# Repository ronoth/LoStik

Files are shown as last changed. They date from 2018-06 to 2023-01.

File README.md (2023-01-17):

# LoStik

LoStik is an affordable, easy to use, LoRaWAN™ compatible device. It lets IoT (Internet of Things) integrators, network testers, and hobbyists get connected to a LoRa® network faster, diagnose network issues more easily, and build new and exciting connected devices.  LoStik is currently available to purchase on [Crowd Supply](https://www.crowdsupply.com/third-venture/lostik) and [Connected Things Store](https://connectedthings.store/gb/search?controller=search&s=lostik).

## Examples

Python examples require Python 3.  Be sure to install the dependiencies in requirements.txt

    pip install -r requirements.txt

### Miniterm

miniterm.py is a light weight terminal emulator that works well with LoRa stick. 
The RN2903/R2483 radios require \r\n line ending and run at 57600 baud.

    ./miniterm.py --echo /dev/ttyUSB0 57600

### Blinky

blinky.py is for testing the user LEDs on the LoRa Stik.  There is a red led tied to GPIO11 and a blue led tied to GPIO10. 

    ./blinky.py  -m blue -d 1 /dev/ttyUSB0

will blink the blue led once per second

    ./blinky.py -m both -d .5 /dev/ttyUSB0

will alternate the blue and red leds every .5 seconds.

### Packet Radio

radio_receiver.py and radio_sender.py are used for sending LoRa packets between two LoRa Stiks without the need for a LoRaWAN gateway.  The included example sends a unix timestamp packet every 2 seconds and the receiver prints the incoming packets to stdout.

## Resources

For detailed infomation about available commands checkout one of the following docs:
* [RN2903 Command Reference](http://ww1.microchip.com/downloads/en/DeviceDoc/40001811A.pdf)
* [RN2843 Command Reference](http://ww1.microchip.com/downloads/en/DeviceDoc/40001784B.pdf)

### GUI
Microchip offers a programm called "Lora Dev Utility" that is part of the [LoRa Development Suite](https://www.microchip.com/developmenttools/ProductDetails/dv164140-1)

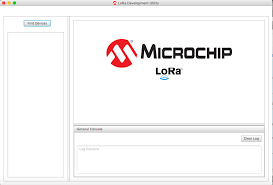
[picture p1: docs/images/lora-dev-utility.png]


## Platform Notes

For platform specific notes see:

* [Windows](docs/windows.md)
* [Mac](docs/mac.md)
* [Linux](docs/linux.md)

## License

### Software

All software and example scripts are MIT licensed.  For details see [LICENSE](blob/master/LICENSE)

### Hardware
Hardware design and schematics are licenede under Creative Commons CC-BY-SA-NC  For details see [hardware/LICENSE.md](blob/master/hardware/LICENSE.md)

### User LEDS

LoStik has two user LEDs that you can control via the UART interface on GPIO10 and GPIO11 and can be accessed using the following commands:

```sys set pindig GPIO10 1``` (turns on blue LED)

```sys set pindig GPIO10 0``` (turns off blue LED)

```sys set pindig GPIO11 1``` (turns on red LED)

```sys set pindig GPIO11 0``` (turns off red LED)

<sup>LoRa® and LoRaWAN™ are trademarks of Semtech Corporation or its subsidiaries.</sup>

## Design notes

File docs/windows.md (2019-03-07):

# CH340G Driver

Windows requires the installation of the CH340 USB to Serial Driver.  [Download Link](http://www.wch.cn/downloads/file/65.html)

Once installed you should should see a new COM port in device manager that appears as a CH340 serial device.

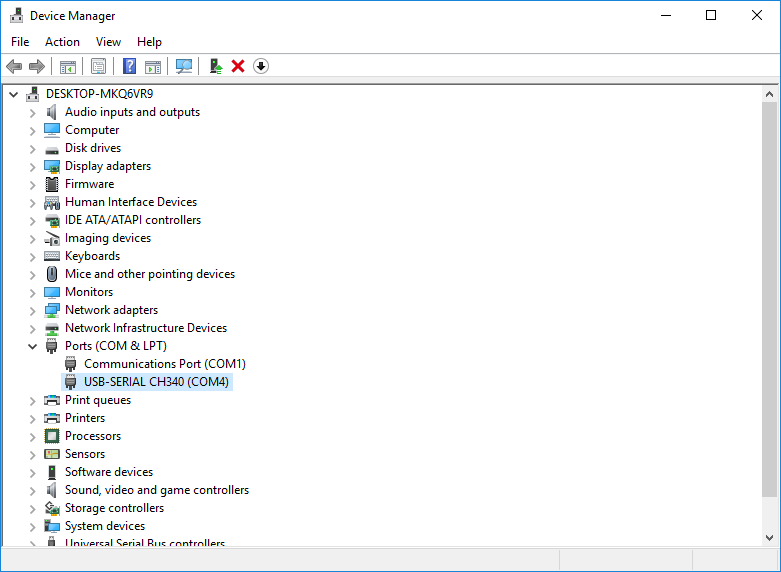
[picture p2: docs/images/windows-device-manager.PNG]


# Terminals

* **Termite** - [Termite](https://www.compuphase.com/software_termite.htm) is a friendly terminal emulator and is the recommended route if you do not wish to install python.  Besure to check the options below, including `Append CR-LF` and `Local echo`.

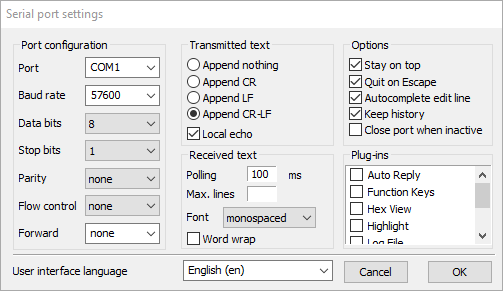
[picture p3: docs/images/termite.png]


* **miniterm.py** - [examples/miniterm.py](../examples/miniterm.py) is a python terminal emulator that is recommended for use along with the python examples provided in this repository.
* **Putty** - Although Putty is very popular, the RN2903/RN2483 require \r\n endings which is not a configuration option in vanilla putty.

# GUI
Microchip offers a programm called "Lora Dev Utility" that is part of the [LoRa Development Suite](https://www.microchip.com/developmenttools/ProductDetails/dv164140-1)



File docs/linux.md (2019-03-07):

# Driver

Most modern Debian distros come with the CH340 serial driver compiled as a kernel module.  WCH offers [Linux driver source](http://www.wch.cn/download/CH341SER_LINUX_ZIP.html), but compilation and installation is not covered here.

# Terminal

There is a python terminal utility located in examples/miniterm.py that is recommended.

Any terminal emulator that can send \r\n should work.  Key settings are:
* baud: 57600
* data bits: 8
* stop bits: 1
* parity: none
* flow control: none

# GUI
Microchip offers a programm called "Lora Dev Utility" that is part of the [LoRa Development Suite](https://www.microchip.com/developmenttools/ProductDetails/dv164140-1)



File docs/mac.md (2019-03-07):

# CH340G Driver

Mac OS X requires the installation of the CH340 USB to Serial Driver.  Please refer to the following repository for installation instructions:

https://github.com/adrianmihalko/ch340g-ch34g-ch34x-mac-os-x-driver

# Terminals

There is a python terminal utility located in examples/miniterm.py that is recommended.  The `screen` commandline utility will also work.  The serial device will be mounted to in the dev directory and appear as `tty.wchusbserial14210` or similar.  

Any terminal emulator that can send \r\n should work.  Key settings are:
* baud: 57600
* data bits: 8
* stop bits: 1
* parity: none
* flow control: none

# GUI
Microchip offers a programm called "Lora Dev Utility" that is part of the [LoRa Development Suite](https://www.microchip.com/developmenttools/ProductDetails/dv164140-1)



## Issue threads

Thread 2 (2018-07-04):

expand README

vielmetti, 2018-07-04:
Some things I'd expect to see in a README

- what this code is for
- who wrote it
- where you can order these parts
- when things are expected to ship
- why you might want it
- what else you might build on top of this system

vielmetti, 2018-07-04:
Some of the details and pictures from https://www.thethingsnetwork.org/forum/t/lora-stik-rn2903-usb-device/14976 would be good to add here too.

vielmetti, 2018-07-04:
Some reference to the RN2903 data sheet at http://ww1.microchip.com/downloads/en/DeviceDoc/50002390E.pdf would be useful too.

lolsborn, 2018-07-09:
Thanks @vielmetti  I have plans to add more example code and an updated read me in the following weeks before the CS campaign closes.

WA4OSH, 2018-12-01:
Some reference to the RN2483 data sheet would also be good for EU868 users.

WA4OSH, 2018-12-01:
Some reference to the PIC18F46K22 is needed
https://www.microchip.com/wwwproducts/en/PIC18F46K22
http://ww1.microchip.com/downloads/en/DeviceDoc/40001412G.pdf

WA4OSH, 2018-12-01:
Some reference to the LoRaWAN Library is needed:
http://ww1.microchip.com/downloads/en/DeviceDoc/40001864B.pdf

WA4OSH, 2018-12-01:
Your LoStik API needs to be documented
  send_cmd(" ")...

  sys set pindig GPIO11 0
      GPIO10 = blue led
      GPIO11 = red led
      0 = off?
      1 = on?

  sys get ver

  radio get freq
  radio get mod
  radio get sf

  radio rx

  radio set pwr 10

...etc.

Where are the LoRaWAN commands?  Are there callbacks to handle the incoming LoRaWAN messages?

lolsborn, 2018-12-01:
Check out the command references linked to in the readme.  

On Sat, Dec 1, 2018 at 11:49 AM -0800, "Konrad Roeder" <notifications@github.com> wrote:

Your LoStik API needs to be documented

send_cmd(" ")...

sys set pindig GPIO11 0

GPIO10 = blue led

GPIO11 = red led

0 = off?

1 = on?

sys get ver

radio get freq

radio get mod

radio get sf

radio rx

radio set pwr 10

...etc.

Where are the LoRaWAN commands?  Are there callbacks to handle the incoming LoRaWAN messages?

—
You are receiving this because you commented.
Reply to this email directly, view it on GitHub, or mute the thread.

WA4OSH, 2018-12-05:
@lolsborn  OK ... then please document at least the action of the system commands that won't be documented in the Microdot document.  For example, there's no indication in the microdot documentation as to which LEDs are connected to what ports.  Yes, I can read a schematic.  But, it's sometimes good to have it all in one place.  Documentation does not need to be a research project for the user.

sys set pindig
GPIO10 = blue led
GPIO11 = red led
0 = off?
1 = on?

lolsborn, 2018-12-08:
Try just sending "sys get ver" to start.  If that doesn't return a
version string then you then you may have an issue with your unit.Sending random text will also return "invalid_command".    Otherwise
your terminal settings look correct.

On Sat, Dec 8, 2018, at 5:28 AM, Konrad Roeder wrote:
> Need a quick "sanity check" for LoStik.

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

Links:

  1. https://github.com/lolsborn/LoStik/issues/2#issuecomment-445459253
  2. https://github.com/notifications/unsubscribe-auth/AADshKnf4MvM_Dock81CCGEflLxNYXU8ks5u276NgaJpZM4VB4Mm

lolsborn, 2018-12-08:
There is a miniterm.py in examples that works well as a test terminal.
If you run python miniter.py <COMPORT> 57600 it is a good way to see if
it's an issue with your existing terminal settings.

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

Links:

  1. https://github.com/lolsborn/LoStik/issues/2#issuecomment-445475790
  2. https://github.com/notifications/unsubscribe-auth/AADshJAOq8612aHca11q8xAIsYhrAeW3ks5u2_cEgaJpZM4VB4Mm

WA4OSH, 2018-12-08:
I had not setup Python 3.7.1 on my machine yet and needed something quicker
to check my LoStik.  Next step, is of course to finish getting Python up
and running.

--Konrad

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

--
Best,
Konrad

Konrad Roeder
425-444-0595 Cell
425-256-2144 Home

lolsborn, 2018-12-09:
Added info about LEDs to readme and have updated docs / examples quite a bit since this ticket was initially created.  I'm going to close it for now.  If there are specific suggestions or PRs please open another issue.

Closed 2018-12-09.

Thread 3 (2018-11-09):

radio_sender.py: invalid_param

dl8bb, 2018-11-09:
Hi folks,
  today I got the two LoStiks from customs and I'm happy to try it out. I cloned the repo and started trying the examples. blinky.py is working with both sticks but I have not much luck with radio_sender.py and radio_receiver.py scripts. It looks like the sender is only working the 1st time and than it says "*invalid_param*" forever.

Here is the output I see:

```
pi@pinebook:~/LoStik/examples$ ./radio_sender.py
ok
RN2483 1.0.4 Oct 12 2017 14:59:25
lora
868100000
sf12
4294967245
ok
ok
ok
ok
ok
radio_tx_ok
ok
invalid_param
ok
ok
invalid_param
ok
ok
invalid_param
ok
ok
invalid_param
^CTraceback (most recent call last):
  File "./radio_sender.py", line 26, in <module>
    time.sleep(2)
KeyboardInterrupt
pi@pinebook:~/LoStik/examples$
```

and the receiver is on a pi2

```
pi@raspberrypi:~/LoStik/examples $ ./radio_receiver.py
connection made
RN2483 1.0.4 Oct 12 2017 14:59:25
4294967245
radio_rx  1541778041
```

Any hints or help for me?

BTW: I modified the parser.add_arguments() call in both files to
```
parser.add_argument('port', nargs='?', default='/dev/ttyUSB0', help="Serial port descriptor")
```
cheers
birko
--

dl8bb, 2018-11-09:
I've added some debug output to the radio_sender.py script and it looks like at some point the LoStik doesn't understand the command *sys set pindig GPIO11 0* any more.
```
pi@raspberrypi:~/LoStik/examples $ ./radio_sender.py
### cmd: sys set pindig GPIO11 0
### response: ok
### cmd: sys get ver
### response: RN2483 1.0.4 Oct 12 2017 14:59:25
### cmd: radio get mod
### response: lora
### cmd: radio get freq
### response: 868100000
### cmd: radio get sf
### response: sf12
### cmd: mac pause
### response: 4294967245
### cmd: radio set pwr 10
### response: ok
### cmd: sys set pindig GPIO11 0
### response: ok
### cmd: sys set pindig GPIO11 1
### response: ok
### cmd: radio tx 1541779677
### response: ok
### cmd: sys set pindig GPIO11 0
### response: ok
### cmd: sys set pindig GPIO11 1
### response: radio_tx_ok
### cmd: radio tx 1541779679
### response: ok
### cmd: sys set pindig GPIO11 0
### response: invalid_param
### cmd: sys set pindig GPIO11 1
### response: ok
### cmd: radio tx 1541779681
### response: ok
### cmd: sys set pindig GPIO11 0
### response: invalid_param
^CTraceback (most recent call last):
  File "./radio_sender.py", line 27, in <module>
    time.sleep(2)
KeyboardInterrupt
pi@raspberrypi:~/LoStik/examples $
```
On the receiver side I only see the 1st transmission.
```
bergt@pinebook:~/LoStik/examples$ ./radio_receiver.py
connection made
RN2483 1.0.4 Oct 12 2017 14:59:25
4294967245
radio_rx  1541779677
```
I changed the sender and receiver to the other computer.

olemd, 2018-11-12:
Adding a slight delay after
`send_cmd("sys set pindig GPIO11 1")`
"works for me".
`time.sleep(.1)`

Removing the whole "sys set pindig GPIO11 1" also works, presumably blinking the LED takes a moment and the stick isn't immediately ready for a new command.

dl8bb, 2018-11-13:
Removing both commands to switch the LED on and off helped.
The short delay of .1 or .2 didn't work for me.
```
    while True:
        time.sleep(2)
#        send_cmd("sys set pindig GPIO11 1")
        send_cmd('radio tx %d' % int(time.time()))
        time.sleep(.1)
#        send_cmd("sys set pindig GPIO11 0")
#        time.sleep(.2)
```

olemd, 2018-11-13:
I suppose this could be related to CPU-speed. I've just tested it on my laptop with a i7-6500U. The .1 sleep delay worked fine there, but I suspect a RPi or other low-end system might not need it while a faster CPU might need an even higher delay. Assuming send_cmd and python itself will take a tiny bit longer to execute on the low-end systems?

liverun, 2018-11-24:
Adding a slight delay after
`send_cmd("sys set pindig GPIO11 1")`
worked for me:
`time.sleep(.1)`

The sender runs on a RPi

lolsborn, 2018-12-09:
Hey guys, somehow this whole thread slipped past me.  I'm going to update the example code to include an additional timeout.  I'm not sure why @dl8bb would need to comment out that code.  @dl8bb have you tried running those commands separately?  It's possible to wait for an "ok" before moving to the next command. I might play around with something like pexcept in python.

lolsborn, 2018-12-10:
I think this commit will fix the issue as well as blink the led on send properly and it also sends a frame counter which makes it easier to catch missed frames on the receive.

Closed 2018-12-10.

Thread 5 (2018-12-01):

PIC18LF46K22 code?

WA4OSH, 2018-12-01:
I don't see the PIC18LF46K22 code in the GitHub.  Does it have API primitives to support LoRaWAN as well as LoRa?

WA4OSH, 2018-12-01:
Please document the API to the PIC18LF46K22 code so that we can develop LoRa (point-to-point) and LoRaWAN connections.

WA4OSH, 2018-12-01:
Does your PIC's LoRaWAN code support OTAA, or is it ABP only?

lolsborn, 2018-12-09:
The default firmware on the RN2903 is UART / text based.  See command reference linked in readme.  It supports both OTAA and ABP class A LoRaWAN.

I'm not going to include any instructions on here for programming via C / MPLab as 99% of people are using this as a test device via the UART interface.  I have had some success programming the PIC18 on the RN2903, but it requires a lot of effort to get setup.  The firmware library for the PIC includes both class A and class C LoRaWAN support.

magillus, 2019-06-13:
I found that firmware of RN2903 1.0.5 at https://www.microchip.com/wwwproducts/en/RN2903 release notes mention class C support with `set class` command

Closed 2018-12-09.

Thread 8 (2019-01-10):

LoStik is not recognised on OSX HighSierra

krital, 2019-01-10:
Hi,

do I need some special FTDI / other driver for LoStik to be recognised under OSX? I have tried both with and without a hub and I get no serial device created.

lolsborn, 2019-01-11:
Could you paste the output of

    system_profiler SPUSBDataType

We're looking for a device that matches Product ID: 0x7523 and Vendor ID: 0x1a86 if we have that it's probably not a hardware issue at least.

Once we know it's not a hardware issue take a look in /dev/tty.*  for some reason the ch340 on my mac shows two devices a tty.usbserial- and tty.wchusbserial  the later is the one you want to connect to.  If you don't see a device there I recommend taking these steps:

https://medium.com/@tony92151/arduino-ch340-chip-driver-for-high-sierra-39e621dae1e4

The terminal requires CRLF which is your terminal app may or may not use by default.  I would recommend starting off using the miniterm.py script in examples mentioned in the readme.

krital, 2019-01-12:
Hello,

its not a hardware issue, I can see the device:

   USB2.0-Serial:

          Product ID: 0x7523
          Vendor ID: 0x1a86
          Version: 2.63
          Speed: Up to 12 Mb/sec
          Location ID: 0x00200000 / 13
          Current Available (mA): 500
          Extra Operating Current (mA): 0

I can also see it with lsusb: Bus 000 Device 013: ID 1a86:7523 1a86 USB2.0-Serial

What is do not see is a serial device under /dev/tty.* hence I can not run any terminal... I did try with minicom initially against /dev/ttyS0 but that is not the correct serial port. I have faced the problem in the past with various boards and I had to install some FTDI drivers.. I understand though that LoStik uses some other chip?

krital, 2019-01-25:
hello, so as the device does not appear, I followed the steps on the medium post above, rebooted my Mac as instructed but I still do not see the device. What do I try next?

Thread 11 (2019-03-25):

LoStik: needs driver in raspberry PI?

neypalma, 2019-03-25:
Hi, i want to use the lostik with my raspberry 3. The raspberry seems to recognize the lostik but i cant connect to serial port.

Mi question is if lostik needs driver installation in raspberry.

Greetings

lolsborn, 2019-03-25:
What distro are you using?

On Mon, Mar 25, 2019 at 8:49 AM -0700, "neypalma" <notifications@github.com> wrote:

Hi, i want to use the lostik with my raspberry 3. The raspberry seems to recognize the lostik but i cant connect to serial port.

Mi question is if lostik needs driver installation in raspberry.

Greetings

—
You are receiving this because you are subscribed to this thread.
Reply to this email directly, view it on GitHub, or mute the thread.

neypalma, 2019-03-25:
> What distro are you using?
Im using rasbian stretch

lolsborn, 2019-03-25:
So I installed rasbian-strech-full on SD card, booted it and the device mounted to /dev/ttyUSB0

Unfortunately I didn't get any further before my RPI A croaked. I'm not sure what happened, but it's no longer with us.

Are you not seeing a device at /dev/ttyUSB0

On Mon, Mar 25, 2019, at 9:14 AM, neypalma wrote:

>> What distro are you using?
>>  Im using rasbian stretch

> —
> You are receiving this because you commented.
> Reply to this email directly, view it on GitHub <https://github.com/ronoth/LoStik/issues/11#issuecomment-476269270>, or mute the thread <https://github.com/notifications/unsubscribe-auth/AADshLC8w90V-xTv48kZnInBeb-xqJwnks5vaPX5gaJpZM4cHOdN>.

neypalma, 2019-03-25:
Hi, yes I see TTYUSB0, I connect to it but can interact with the board. There is no message. The device seems to be hanged after making the connection

lolsborn, 2019-03-25:
What terminal program are you using to connect?

On Mon, Mar 25, 2019, at 1:20 PM, neypalma wrote:
> Hi, yes I see TTYUSB0, I connect to it but can interact with the board. There is no message. The device seems to be hanged after making the connection

> —
> You are receiving this because you commented.
> Reply to this email directly, view it on GitHub <https://github.com/ronoth/LoStik/issues/11#issuecomment-476361262>, or mute the thread <https://github.com/notifications/unsubscribe-auth/AADshLQsoiz6fHpuyw-gmZKWJUrlx6-kks5vaS-IgaJpZM4cHOdN>.

neypalma, 2019-03-25:
I try putty and minicom

lolsborn, 2019-03-25:
Putty is known to have issues because the RN2903 requires \r\n endings.

I'm not really familiar with minicom. I would recommend trying the miniterm.py script in the examples directory first. There is also a gui program released by Microchip, but requires Java to run.

There is a bit more info on how to run miniterm and where to download the LoRa Development Suite Gui here.
https://github.com/ronoth/LoStik

On Mon, Mar 25, 2019, at 2:02 PM, neypalma wrote:
> I try putty and minicom

> —
> You are receiving this because you commented.
> Reply to this email directly, view it on GitHub <https://github.com/ronoth/LoStik/issues/11#issuecomment-476376205>, or mute the thread <https://github.com/notifications/unsubscribe-auth/AADshBlG82puP1Db75PO8vWjiiwAiiZdks5vaTlqgaJpZM4cHOdN>.

neypalma, 2019-03-26:
@lolsborn  i have had success using picocom program and running it like this

> picocom --omap crcrlf,delbs --imap crcrlf,delbs -c -b 57600 -r -l /dev/ttyUSB0

Greetings

Closed 2019-03-31.

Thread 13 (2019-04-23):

Does LoStik work with Android?

DimaBond174, 2019-04-23:
Hi

Can i connect LoStik device to Android phone and work with them through OTG?
Will it work for Android 8, 9 (API > 24)?
Is the power supply from the phone's OTG enough for  to work the LoStik?

Thanks in advance for the answers..

lolsborn, 2019-04-23:
I don’t know anyone who has tried with Android. It is a serial text device using a CH340 usb to serial converter. It works with other flavors of Linux including Raspian, but I don’t currently have an Android device to test on.

On Mon, Apr 22, 2019, at 6:58 PM, Dmitriy Bondarenko wrote:
> Hi

> Can i connect LoStik device to Android phone and work with them through OTG?
>  Will it work for Android 8, 9 (API > 24)?
>  Is the power supply from the phone's OTG enough for to work the LoStik?

> Thanks in advance for the answers..

> —
> You are receiving this because you are subscribed to this thread.
> Reply to this email directly, view it on GitHub <https://github.com/ronoth/LoStik/issues/13>, or mute the thread <https://github.com/notifications/unsubscribe-auth/AAAOZBA6DMBXDDMWEDYFPLTPRZUMTANCNFSM4HHT5MHA>.

lolsborn, 2019-04-23:
This app claims to support FTDI and CH340G devices so it seems like it's a possibility. https://play.google.com/store/apps/details?id=com.liorhass.android.usbterminal.free&hl=en_US

Closed 2019-04-29.

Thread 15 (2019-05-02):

Lorawan example throws 'ReaderThread' object has no attribute 'read'

lolsborn, 2019-05-02:
Per Bob P.

We ordered a couple of LoSticks from Tindie and tried the example software from the repo, however we cannot get lorawan.py example to work:

    python3 lorawan.py --joinmode otaa --appeui "xxxxxx" --appkey "xxxx" --deveui "xxxxx" /dev/tty.usbserial-14120

Running this on a MacOs with python3 and getting the following error:
```
Connection to LoStik established
mac get appeui
'ReaderThread' object has no attribute 'read'
Lost connection to serial device
Traceback (most recent call last):
File "lorawan.py", line 118, in <module>
with ReaderThread(ser, PrintLines) as protocol:
File "/anaconda3/lib/python3.6/site-packages/serial/threaded/__init__.py", line 250, in __enter__
raise RuntimeError('connection_lost already called')
RuntimeError: connection_lost already called
```
Do you know what I might be doing wrong? (application key supplied in the argument is changed a bit, but functions as example)

Thank you in advance.

Best Regards,
Bob

lolsborn, 2019-05-02:
This should be fixed again in ffd36ecc15fc95545216bb15b1c78bc6cfa9063d waiting on access to a Gateway this afternoon to test and confirmation from Bob.

lolsborn, 2019-05-03:
Ok, I've tested the latest commit to master and everything seems to be in order.

Closed 2019-06-14.

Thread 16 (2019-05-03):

mRuby

zwykl3, 2019-05-03:
Is possible using mRuby on this device?

lolsborn, 2019-05-03:
Are you inquiring about LoStik or LoDev?

Also, I'm assuming you are talking about MicroRuby and not mRuby?

LoStik is a device that allows you to send LoRa messages by talking to it over UART and won't run custom code. It is possible to upload your own firmware to the on-board PIC micro, but I don't know anyone besides myself who has tried it.

LoDev is a micro-controller board using a LoRa/STM32 SoC and it maybe possible tot run MicroRuby on it. No one has attempted it to my knowledge. I have spent some time on MicroPython, but so far the tests haven't been super promising 192k flash is a bit tight for MicroPython. It may still be possible, but will require some non-trivial trimming.

On Fri, May 3, 2019, at 2:42 AM, zwykl3 wrote:
> Is possible using mRuby on this device?

> —
> You are receiving this because you are subscribed to this thread.
> Reply to this email directly, view it on GitHub <https://github.com/ronoth/LoStik/issues/16>, or mute the thread <https://github.com/notifications/unsubscribe-auth/AAAOZBBSEYIFKLOSWX7A3XLPTQCJVANCNFSM4HKSRJYQ>.

zwykl3, 2019-05-05:
I'm interesting Lora communications. In my opinion internet isnt free.
mRuby need 400Kb memory to run. MicroRuby is not a oficial way to using Ruby. I like Ruby and write some extension in C. mRuby (and mrubyc) are created in C. Every procesor who have c compiler and  malloc can run mRuby.

Lostick for me are great way to connect people like a old BBS or services similar usenet or irc/communicators.
For example how connect pygo, gotenna and Lostick? Idea need more flexible and more programmers

Meybe in Lostick 2.0 You put more RAM.

Closed 2019-06-14.

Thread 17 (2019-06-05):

Problem with lorawan.py

aditya767, 2019-06-05:
I am trying to send data packet from my windows PC through LoStik to My raspberry Pi gateway
The status for transmission of packet to gateway is OK but I am not able to receive anything on gateway. I am using US configuration file and ABP. I ran configure.py and then lorawan.py
One more doubt the default 923.3 Mhz frequency is uplink or downlink frequency. How to configure to a particular uplink frequency? Also what all codes from the repository should be run to be able to send packet to gateway?
This is the output I get:

Connection to LoStik established
mac set devaddr 260211EE
mac set appskey 5C5A6E6DEC9EBF6F01575B7FFC508B07
mac set nwkskey 250AAA4CF48437307EF5ABE39EAB9954
mac join abp
radio get freq
radio set freq 904500000
mac pause
mac resume
radio set pwr 10
radio get freq
STATUS: ok
STATUS: ok
STATUS: ok
STATUS: ok
STATUS: accepted
UPDATING STATE to connected
STATUS: 923300000
STATUS: ok
STATUS: 4294967245
STATUS: ok
STATUS: ok
STATUS: 904500000
mac tx uncnf 1 1559768554
STATUS: ok
STATUS: mac_tx_ok
mac tx uncnf 1 1559768564
STATUS: ok
STATUS: mac_tx_ok
mac tx uncnf 1 1559768575
STATUS: ok
STATUS: mac_tx_ok
mac tx uncnf 1 1559768585
STATUS: ok
STATUS: mac_tx_ok
mac tx uncnf 1 1559768596
STATUS: ok
STATUS: mac_tx_ok
mac tx uncnf 1 1559768606
STATUS: ok
STATUS: mac_tx_ok
mac tx uncnf 1 1559768617
STATUS: ok
STATUS: mac_tx_ok
mac tx uncnf 1 1559768627
STATUS: ok
STATUS: mac_tx_ok
mac tx uncnf 1 1559768638
STATUS: ok
STATUS: mac_tx_ok
mac tx uncnf 1 1559768648
STATUS: ok
STATUS: mac_tx_ok
mac tx uncnf 1 1559768659
STATUS: ok
STATUS: mac_tx_ok
mac tx uncnf 1 1559768669
STATUS: ok
STATUS: mac_tx_ok
mac tx uncnf 1 1559768680
STATUS: ok
STATUS: mac_tx_ok
mac tx uncnf 1 1559768690
STATUS: ok
STATUS: mac_tx_ok
mac tx uncnf 1 1559768701
STATUS: ok
STATUS: mac_tx_ok
mac tx uncnf 1 1559768711
STATUS: ok
STATUS: mac_tx_ok
mac tx uncnf 1 1559768722
STATUS: ok
STATUS: mac_tx_ok
mac tx uncnf 1 1559768732
STATUS: ok
STATUS: mac_tx_ok
mac tx uncnf 1 1559768743
STATUS: ok
STATUS: mac_tx_ok
mac tx uncnf 1 1559768753
STATUS: ok
STATUS: mac_tx_ok
mac tx uncnf 1 1559768764
STATUS: ok
STATUS: mac_tx_ok
mac tx uncnf 1 1559768774
STATUS: ok
STATUS: mac_tx_ok
mac tx uncnf 1 1559768785
STATUS: ok
STATUS: mac_tx_ok
mac tx uncnf 1 1559768795
STATUS: ok
STATUS: mac_tx_ok
mac tx uncnf 1 1559768806
STATUS: ok
STATUS: mac_tx_ok
mac tx uncnf 1 1559768816
STATUS: ok
STATUS: mac_tx_ok
mac tx uncnf 1 1559768827
STATUS: ok
STATUS: mac_tx_ok
mac tx uncnf 1 155976883

aditya767, 2019-06-06:
I increased the frequency deviation it worked. Sorry, for trouble

aditya767, 2019-06-06:
I tried my gateway with Arduino leonardo with RN2903, it was receiving packets but Lostik is sending packet but not to my gateway but other gateways as I am able to see packets in The things network. What could be the possible problem with my gateway?
I am using Rpi dual channel gateway.

Closed 2019-07-18.

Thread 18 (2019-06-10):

No data received with example codes

m0nkeyc0de, 2019-06-10:
Hello, beginning of the year I bought a pair of 868MHz LoStik and now I'm trying to have the examples working.

It turns out that the "radio_receiver.py" doesn't receive any data. I modified it to print every call to "handle_line" and here is the output I get :
```
(LoEnv) thor@valhalla:~/Geeking/LoStik/examples$ ./radio_receiver.py /dev/ttyUSB1
connection made
handle_line(data='RN2483 1.0.4 Oct 12 2017 14:59:25')
RN2483 1.0.4 Oct 12 2017 14:59:25
handle_line(data='4294967245')
4294967245
handle_line(data='ok')
handle_line(data='ok')
handle_line(data='ok')
handle_line(data='ok')
handle_line(data='ok')
handle_line(data='busy')
handle_line(data='ok')
handle_line(data='ok')
handle_line(data='busy')
handle_line(data='radio_err')
handle_line(data='ok')
handle_line(data='radio_err')
handle_line(data='ok')
... and so on...
```
The sender seems to work be working fine :
```
(LoEnv) thor@valhalla:~/Geeking/LoStik/examples$ ./radio_sender.py /dev/ttyUSB0
radio tx 5cfea21d0
radio tx 5cfea21f1
radio tx 5cfea2212
radio tx 5cfea2243
radio tx 5cfea2264
radio tx 5cfea2285
radio tx 5cfea22a6
radio tx 5cfea22d7
radio tx 5cfea22f8
radio tx 5cfea2319
radio tx 5cfea234a
radio tx 5cfea236b
radio tx 5cfea238c
```

I tried to invert LoStik roles but it doesn't change anything.
Any clue ?

lolsborn, 2019-06-13:
I was able to reproduce this issue this morning. It seems to only affect the EU version for some reason, not the US radios. I'm guessing more configuration is required on startup, but it has been tested with earlier versions of this code so I'm not sure what is going on. I'll continue to investigate and hopefully push a patch today.

On Mon, Jun 10, 2019, at 11:45 AM, m0nkeyc0de wrote:
> Hello, beginning of the year I bought a pair of 868MHz LoStik and now I'm trying to have the examples working.

> It turns out that the "radio_receiver.py" doesn't receive any data. I modified it to print every call to "handle_line" and here is the output I get :

> `(LoEnv) thor@valhalla:~/Geeking/LoStik/examples$ ./radio_receiver.py /dev/ttyUSB1
connection made
handle_line(data='RN2483 1.0.4 Oct 12 2017 14:59:25')
RN2483 1.0.4 Oct 12 2017 14:59:25
handle_line(data='4294967245')
4294967245
handle_line(data='ok')
handle_line(data='ok')
handle_line(data='ok')
handle_line(data='ok')
handle_line(data='ok')
handle_line(data='busy')
handle_line(data='ok')
handle_line(data='ok')
handle_line(data='busy')
handle_line(data='radio_err')
handle_line(data='ok')
handle_line(data='radio_err')
handle_line(data='ok')
... and so on...
`
> The sender seems to work be working fine :

> `(LoEnv) thor@valhalla:~/Geeking/LoStik/examples$ ./radio_sender.py /dev/ttyUSB0
radio tx 5cfea21d0
radio tx 5cfea21f1
radio tx 5cfea2212
radio tx 5cfea2243
radio tx 5cfea2264
radio tx 5cfea2285
radio tx 5cfea22a6
radio tx 5cfea22d7
radio tx 5cfea22f8
radio tx 5cfea2319
radio tx 5cfea234a
radio tx 5cfea236b
radio tx 5cfea238c
`

> I tried to invert LoStik roles but it doesn't change anything.
>  Any clue ?

> —
> You are receiving this because you are subscribed to this thread.
> Reply to this email directly, view it on GitHub <https://github.com/ronoth/LoStik/issues/18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>, or mute the thread <https://github.com/notifications/unsubscribe-auth/AAAOZBENH5KIMX4EZ2263R3PZ2ON7ANCNFSM4HWWJDDA>.

lolsborn, 2019-06-13:
Could you test out this branch and see if it works for you? https://github.com/doismellburning/LoStik/tree/feature/LineReader-send-example

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

>> It turns out that the "radio_receiver.py" doesn't receive any data. I modified it to print every call to "handle_line" and here is the output I get :

>> `(LoEnv) thor@valhalla:~/Geeking/LoStik/examples$ ./radio_receiver.py /dev/ttyUSB1
connection made
handle_line(data='RN2483 1.0.4 Oct 12 2017 14:59:25')
RN2483 1.0.4 Oct 12 2017 14:59:25
handle_line(data='4294967245')
4294967245
handle_line(data='ok')
handle_line(data='ok')
handle_line(data='ok')
handle_line(data='ok')
handle_line(data='ok')
handle_line(data='busy')
handle_line(data='ok')
handle_line(data='ok')
handle_line(data='busy')
handle_line(data='radio_err')
handle_line(data='ok')
handle_line(data='radio_err')
handle_line(data='ok')
... and so on...
`
>> The sender seems to work be working fine :

>> `(LoEnv) thor@valhalla:~/Geeking/LoStik/examples$ ./radio_sender.py /dev/ttyUSB0
radio tx 5cfea21d0
radio tx 5cfea21f1
radio tx 5cfea2212
radio tx 5cfea2243
radio tx 5cfea2264
radio tx 5cfea2285
radio tx 5cfea22a6
radio tx 5cfea22d7
radio tx 5cfea22f8
radio tx 5cfea2319
radio tx 5cfea234a
radio tx 5cfea236b
radio tx 5cfea238c
`
>>

>> I tried to invert LoStik roles but it doesn't change anything.
>> Any clue ?
>>

>> —
>> You are receiving this because you are subscribed to this thread.
>> Reply to this email directly, view it on GitHub <https://github.com/ronoth/LoStik/issues/18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>, or mute the thread <https://github.com/notifications/unsubscribe-auth/AAAOZBENH5KIMX4EZ2263R3PZ2ON7ANCNFSM4HWWJDDA>.

>

lolsborn, 2019-06-14:
This should be fixed in b12f1be I merged the fork that I mentioned previously and it seems to work.

m0nkeyc0de, 2019-06-14:
That was fast and efficient ! Now it works perfectly :+1:
Many thanks for your help

Closed 2019-06-14.

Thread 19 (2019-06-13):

Lora Class C Example

gsvitak, 2019-06-13:
Hello

Do you have a sample or a suggestion on how to set the device to be a Class C Device?

Thanks
Greg

lolsborn, 2019-06-14:
If you take a look at the latest command reference http://ww1.microchip.com/downloads/en/DeviceDoc/RN2903%20LoRa%20Technology%20Module%20Command%20Reference%20User%20Guide-DS40001811B.pdf

There is a command ```mac set class c``` that should do the trick, but you'll have to first upgrade to 1.0.5 firmware using the LoRa Development Suite GUI https://www.microchip.com/developmenttools/ProductDetails/dv164140-1

gsvitak, 2019-06-14:
thank you!!

gsvitak, 2019-06-16:
@lolsborn I cannot find the place to download firmware version 1.0.5.

lolsborn, 2019-06-16:
Are you using the RN2903 (US) or RN2843 (EU)?

Here is the US version link:
https://www.microchip.com/wwwproducts/en/RN2903

If you go to *software *you'll want to download two things

1) LoRa Development Suite (You'll use this GUI to flash the device)
2) RN2903 Firmware v1.0.5 <http://ww1.microchip.com/downloads/en/DeviceDoc/RN2903_1.0.5_Nov_06_2018_10.45.27.zip>

There are two copies of the firmware one is the "unified" version which includes the bootloader which is used for flashing using a Pic programmer. You want the other one, that one doesn't contain the bootloader and is used for programming over USB.

On Sun, Jun 16, 2019, at 11:24 AM, Greg Svitak wrote:
> @lolsborn <https://github.com/lolsborn> I cannot find the place to download firmware version 1.0.5.

> —
> You are receiving this because you were mentioned.
> Reply to this email directly, view it on GitHub <https://github.com/ronoth/LoStik/issues/19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>, or mute the thread <https://github.com/notifications/unsubscribe-auth/AAAOZBATU6SF2L7LNEOBZF3P22AM3ANCNFSM4HYBIGHQ>.

camilo-17, 2019-12-10:
Hello excuse me english I want to know if everyone knows how read the value that sends the LoRa server in the node. I configure the RN2903a to class c and it responds ok, in class a it works correctly, Thanks.

Closed 2019-06-14.

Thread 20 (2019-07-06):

How to use the miniterm?

llorllale, 2019-07-06:
I'm having trouble using `miniterm` to send commands to the LoStik. I'm on Ubuntu 16.04 and using `xterm-256color`.

`miniterm` seems to run fine - I just can't make it execute any of the commands I input. I expect that when I press the Enter key, the command would be sent to the LoStik and I would receive a response. Am I doing something wrong?

Here's an example of what I mean. Notice the cursor about 4 lines below the command - that's me pressing the Enter key several times:

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

llorllale, 2019-07-06:
FYI `blinky.py` runs fine

lolsborn, 2019-07-08:
Sorry for the late reply.  The command you are sending is correct.  Can you try sending `sys get ver`?  The command you are sending should still reply with "OK", but get ver at least returns something more substantial.

I have had one other support request recently where a guy was running things just fine, but having issues with mini-term and then plugged it into a different USB port or something and then it worked fine and continued working when plugged in the old port.  I don't know if it will fix your issue here as I haven't quite figured out what causes it and it seems kind of random.  My best guess is a driver issue in the CH340 code.

lolsborn, 2019-07-18:
Would love to know if you were able to work this out.  For now I'm going to close this ticket, but please re-open if you have additional info.  If you suspect it is faulty hardware send an email to steven@ronoth.com

LalaDK, 2020-02-04:
I had similar problems with miniterm.py. I use Terminator as my default terminal emulator, but that didn't work. Then I tried xterm and then everything worked!
Hope that helps !

lolsborn, 2020-02-04:
Terminator works well, but you have to send \r\n line endings

On Tue, Feb 4, 2020, at 4:45 AM, Mads Dam Eckardt Jensen wrote:

> I had similar problems with miniterm.py. I use Terminator as my default terminal emulator, but that didn't work. Then I tried xterm and then everything worked!
>  Hope that helps !

> —
> You are receiving this because you modified the open/close state.
> Reply to this email directly, view it on GitHub <https://github.com/ronoth/LoStik/issues/20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>, or unsubscribe <https://github.com/notifications/unsubscribe-auth/AAAOZBEFDYPWRCH4WFG4I3LRBFPNNANCNFSM4H6UL5BA>.

gudsi, 2020-04-17:
Hi!
I have the same issue as well.
I am trying to use miniterm via cygwin to send commands to lostik which is plugged to my raspberry. Connect Script works fine, but manual commands to not work.
Can you help me?

lolsborn, 2020-04-17:
What are you using to connect manually?

On Fri, Apr 17, 2020, at 7:05 AM, gudsi wrote:
>

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

> —
> You are receiving this because you modified the open/close state.
> Reply to this email directly, view it on GitHub <https://github.com/ronoth/LoStik/issues/20#issuecomment-615263196>, or unsubscribe <https://github.com/notifications/unsubscribe-auth/AAAOZBAON63YS4YMERHRWULRNBOZNANCNFSM4H6UL5BA>.

gudsi, 2020-04-18:
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

Pressing enter, but nothing happens

lolsborn, 2020-04-18:
This looks like it's potentially a hardware failure mode that I've seen in the past. Could you email steven@ronoth.com and we can see what to do about it and if we're going to need to mail out a replacement.

On Sat, Apr 18, 2020, at 1:16 AM, gudsi wrote:
>

> image <https://user-images.githubusercontent.com/34402250/79632138-aba6d300-815d-11ea-9b91-9b1e2c215ef3.png>

> Pressing enter, but nothing happens

> —
> You are receiving this because you modified the open/close state.
> Reply to this email directly, view it on GitHub <https://github.com/ronoth/LoStik/issues/20#issuecomment-615738267>, or unsubscribe <https://github.com/notifications/unsubscribe-auth/AAAOZBC5QUKU5LDSRGNETTTRNFOXLANCNFSM4H6UL5BA>.

gudsi, 2020-04-19:
Thanks for your quick answer.
The funny thing, I did a reboot and now it works. But my stick is only sending with SF12. Could this issue be related to that hardware topic?

lolsborn, 2020-04-19:
Generally, if the device turns on and replies to commands it is fine. I've seen 2-3 other devices (maybe 1 per 2,000) which enumerate over USB, but never print anything on the console. It's more common that people are using Putty or some terminal that only sends \n and not \r\n so I have to rule that out, but since you're using the mini-term included I was leaning toward that. So if you are sending commands and getting replies it's probably not a hardware problem but a configuration issue.

You say it's only sending on SF12? So when you try to change the spread factor it's not working? Are you running the radio send/receive examples or trying to connect over LoRaWAN?

On Sat, Apr 18, 2020, at 9:39 PM, gudsi wrote:
>

> Thanks for your quick answer.
>  The funny thing, I did a reboot and now it works. But my stick is only sending with SF12. Could this issue be related to that hardware topic?

> —
> You are receiving this because you modified the open/close state.
> Reply to this email directly, view it on GitHub <https://github.com/ronoth/LoStik/issues/20#issuecomment-616029302>, or unsubscribe <https://github.com/notifications/unsubscribe-auth/AAAOZBBXL6CSS7UIWWMYRELRNJ6BTANCNFSM4H6UL5BA>.

gudsi, 2020-04-19:
Yes. Sending commands and getting replies is working fine now.

I am able to adapt the SF via miniterm. If I send data afterwards, I see them arriving, but with SF 12.

Here is a screenshot of the commands I am sending.
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

I am not working with the sender and receiver examples. I am conntected to a LoRa network

lolsborn, 2020-04-19:
Huh, that is pretty curious. What kind of gateway are you using?

On Sat, Apr 18, 2020, at 11:55 PM, gudsi wrote:
>

> Yes. Sending commands and getting replies is working fine now.

> I am able to adapt the SF via miniterm. If I send data afterwards, I see them arriving, but with SF 12.

> Here is a screenshot of the commands I am sending. image <https://user-images.githubusercontent.com/34402250/79681530-4c0efd00-821b-11ea-9f18-6bccbc123377.png>

> I am not working with the sender and receiver examples. I am conntected to a LoRa network

> —
> You are receiving this because you modified the open/close state.
> Reply to this email directly, view it on GitHub <https://github.com/ronoth/LoStik/issues/20#issuecomment-616059490>, or unsubscribe <https://github.com/notifications/unsubscribe-auth/AAAOZBB3Z4MPQNYXYFUJZ3DRNKN7FANCNFSM4H6UL5BA>.

gudsi, 2020-04-19:
CISCO IXM-800 is in use.

gudsi, 2020-04-20:
Does the Stick maybe adapt the SF if the signal is bad?

lolsborn, 2020-04-20:
I haven't had time to look into this really closely. I'm pretty sure the module will change to SF12 during OTAA negotiation. It's possible that it is stomping on whatever setting you added manually during OTAA, but based on your comments earlier it's staying in SF12 even when you change it after you are connected?

On Mon, Apr 20, 2020, at 4:19 AM, gudsi wrote:
>

> Does the Stick maybe adapt the SF if the connection is bad?

> —
> You are receiving this because you modified the open/close state.
> Reply to this email directly, view it on GitHub <https://github.com/ronoth/LoStik/issues/20#issuecomment-616485777>, or unsubscribe <https://github.com/notifications/unsubscribe-auth/AAAOZBFZFBTHJCAMQ7IGADLRNQVT7ANCNFSM4H6UL5BA>.

gudsi, 2020-04-21:
Yes. I changed it, after I was connected.
So first, OTAA, next sending payloads. As mentioned, they are only sent with SF12. No matter which SF is configured via Miniterm.
I hope, you can help me. I am really stuck

lolsborn, 2020-04-23:
Sorry for the delay. Unfortunately, I don't have an answer for you yet. I'm posting on the Microchip forums and might do the same on the TTN forums and see if anyone has run into a similar issue with the RN2903 / RN2843. I'll keep you updated.

On Tue, Apr 21, 2020, at 10:58 AM, gudsi wrote:
>

> Yes. I changed it, after I was connected.
>  So first, OTAA, next sending payloads. As mentioned, they are only sent with SF12. No matter which SF is configured via Miniterm.
>  I hope, you can help me. I am really stuck

> —
> You are receiving this because you modified the open/close state.
> Reply to this email directly, view it on GitHub <https://github.com/ronoth/LoStik/issues/20#issuecomment-617320208>, or unsubscribe <https://github.com/notifications/unsubscribe-auth/AAAOZBH47IB7W6HDM7TL2B3RNXNDJANCNFSM4H6UL5BA>.

gudsi, 2020-04-27:
Good news. Finally I am sending with a better SF.
I am using ADR and started to send every 20 minutes. SF is getting better and is now at SF9 or 8.

lolsborn, 2020-04-27:
This is great news. I'm interested in what you did to fix it. You just turned ADR on?

On Mon, Apr 27, 2020, at 1:39 AM, gudsi wrote:
>

> Good news. Finally I am sending with a better SF.
>  I am using ADR and started to send every 20 minutes. SF is getting better and is now at SF9 or 8.

> —
> You are receiving this because you modified the open/close state.
> Reply to this email directly, view it on GitHub <https://github.com/ronoth/LoStik/issues/20#issuecomment-619824774>, or unsubscribe <https://github.com/notifications/unsubscribe-auth/AAAOZBDX6CF5QUUUZR3XIC3ROVADVANCNFSM4H6UL5BA>.

Closed 2019-07-18.

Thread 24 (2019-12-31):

Appkey invalid in lorawan_sender.py

gudsi, 2019-12-31:
Hi!

I am trying to connect my LoStik to The Things network. I tried to run lorawa_sender.py
(https://github.com/ronoth/LoStik/blob/4b109759486caca33381d06ae525d0ba2a6854f1/examples/lorawan_sender.py)

I always get the error message
 error: argument --appkey/-a: invalid <lambda> value

Can someone help me to solve that?

Thanks a lot

lolsborn, 2019-12-31:
Can you share what you are running via the command line?

There is also a script called configure.py which will read the settings in ttn-us.conf or ttn-eu.conf and configure the channels/credentials on your device for The Things Network. All you have to do is edit the conf file to suit your needs and run the configure.py script.

On Tue, Dec 31, 2019, at 1:03 AM, gudsi wrote:
> Hi!

> I am trying to connect my LoStik to The Things network. I tried to run lorawa_sender.py
>  (https://github.com/ronoth/LoStik/blob/4b109759486caca33381d06ae525d0ba2a6854f1/examples/lorawan_sender.py)

> I always get the error message
>  error: argument --appkey/-a: invalid value

> Can someone help me to solve that?

> Thanks a lot

> —
> You are receiving this because you are subscribed to this thread.
> Reply to this email directly, view it on GitHub <https://github.com/ronoth/LoStik/issues/24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>, or unsubscribe <https://github.com/notifications/unsubscribe-auth/AAAOZBHAHHGVKCQ4XW4P6FTQ3MDGDANCNFSM4KBT3W3Q>.

gudsi, 2020-01-01:
Thanks a lot for your quick answer!

I am trying to run it via Pycharm with this Run Parameters:
--payload 1234 --appkey 10DE087B0D8E71B28CD7409B372A2606 --deveui 0004A30B002374AB --appeui 70B3D57ED0027B03 COM3

I also tried to run the configuration first. After adapting the appkey, deveui and appeui in ttn-eu.conf, running configure.py raises an exception
configparser.NoOptionError: No option 'appeui' in section: 'otaa'

lolsborn, 2020-01-02:
The ttn-eu.conf looks like it's not as complete as the US version. If you look at the US conf you can copy and paste the bits you need for OTAA into the eu config and update them with your credentials.

On Wed, Jan 1, 2020, at 1:54 AM, gudsi wrote:
> Thanks a lot for your quick answer!

> I am trying to run it via Pycharm with this Run Parameters:
>  --payload 1234 --appkey 10DE087B0D8E71B28CD7409B372A2606 --deveui 0004A30B002374AB --appeui 70B3D57ED0027B03 COM3

> I also tried to run the configuration first. After adapting the appkey, deveui and appeui in ttn-eu.conf, running configure.py raises an exception
>  configparser.NoOptionError: No option 'appeui' in section: 'otaa'

> —
> You are receiving this because you commented.
> Reply to this email directly, view it on GitHub <https://github.com/ronoth/LoStik/issues/24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>, or unsubscribe <https://github.com/notifications/unsubscribe-auth/AAAOZBAVDKYILIBP7GHRVITQ3RR5JANCNFSM4KBT3W3Q>.

lolsborn, 2020-01-02:
I'm not sure why running the lorawan_sender script you linked would return invalid appkey unless you had the wrong credential.  Is there any reason you are using that script instead of the one in master https://github.com/ronoth/LoStik/blob/master/examples/lorawan.py ? I know that script worked in the past, but the one in master has been tested far more.

gudsi, 2020-01-03:
I added the other channels to my .conf like that
ch16 = , off
ch17 = , off
ch18 = , off
....
ch71 = , off

But still there is the error _configparser.NoOptionError: No option 'appeui' in section: 'otaa'_

I also tried to run the lorawan.py which gives following output
_Connection to LoStik established
mac set appeui XXX
mac set appkey XXX
mac set deveui XXX
mac join otaa
STATUS: ok
STATUS: ok
STATUS: ok
STATUS: ok
STATUS: denied_

I am sorry, but I really do not know, what is going wrong here.

> The ttn-eu.conf looks like it's not as complete as the US version. If you look at the US conf you can copy and paste the bits you need for OTAA into the eu config and update them with your credentials.
> […](#)

lolsborn, 2020-01-03:
What gateway are you using?

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

> But still there is the error *configparser.NoOptionError: No option 'appeui' in section: 'otaa'*

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

> I am sorry, but I really do not know, what is going wrong here.

>> The ttn-eu.conf looks like it's not as complete as the US version. If you look at the US conf you can copy and paste the bits you need for OTAA into the eu config and update them with your credentials.
>> … <https://www.fastmail.com/mail/compose?u=3f61409c#>

> —
> You are receiving this because you commented.
> Reply to this email directly, view it on GitHub <https://github.com/ronoth/LoStik/issues/24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>, or unsubscribe <https://github.com/notifications/unsubscribe-auth/AAAOZBFMPY5SBQGM6H5IYTDQ33LFZANCNFSM4KBT3W3Q>.

gudsi, 2020-01-03:
Sorry for the stupid answer, but I don´t know. How can I configure that?

lolsborn, 2020-01-03:
LoRaWAN is an authentication, addressing, and management layer on top of LoRa radio that requires a gateway to manage. If you don't have something that resembles a router to receive your LoRa messages you probably don't need LoRaWAN.

You can still use LoRa radios to form simple single channel, point-to-point networks. The other send and receive examples included do that.

On Thu, Jan 2, 2020, at 11:30 PM, gudsi wrote:
> Sorry for the stupid answer, but I don´t know. How can I configure that?

> —
> You are receiving this because you commented.
> Reply to this email directly, view it on GitHub <https://github.com/ronoth/LoStik/issues/24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>, or unsubscribe <https://github.com/notifications/unsubscribe-auth/AAAOZBBGFLUQCBYB23QSP2TQ33SQFANCNFSM4KBT3W3Q>.

gudsi, 2020-01-03:
Thanks for your answer.
I think, I am a bit confused.
I want to build a moisture sensor application with RaspberryPi and using the LoStik to send the data. I thought I can use TTN to send data there. Did I get it wrong?

lolsborn, 2020-01-03:
So you are connecting LoStik to RPI and the moisture sensor speaks LoRa and relays it back?

On Fri, Jan 3, 2020, at 9:18 AM, gudsi wrote:

> Thanks for your answer.
>  I think, I am a bit confused.
>  I want to build a moisture sensor application with RaspberryPi and using the LoStik to send the data. I thought I can use TTN to send data there. Did I get it wrong?

> —
> You are receiving this because you commented.
> Reply to this email directly, view it on GitHub <https://github.com/ronoth/LoStik/issues/24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>, or unsubscribe <https://github.com/notifications/unsubscribe-auth/AAAOZBEOJ53AURD2YMTBX5LQ35XO7ANCNFSM4KBT3W3Q>.

gudsi, 2020-01-03:
Yes. The sensor collects data and sends it via LoRa payload to TTN.

lolsborn, 2020-01-03:
could you share what sensor you are using?

On Fri, Jan 3, 2020, at 9:29 AM, gudsi wrote:
> Yes. The sensor collects data and sends it via LoRa payload to TTN.

> —
> You are receiving this because you commented.
> Reply to this email directly, view it on GitHub <https://github.com/ronoth/LoStik/issues/24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>, or unsubscribe <https://github.com/notifications/unsubscribe-auth/AAAOZBBOAAMMP7UYS5IX4A3Q35YWHANCNFSM4KBT3W3Q>.

gudsi, 2020-01-04:
I will use this one

gudsi, 2020-03-30:
An update from my side
I finally was able to connect with gateway via Termite and lorawan.py via my pc. But I use LoStik on Raspberry, I get denied or no_channel_free.
Any ideas what I am doing wrong?

lolsborn, 2020-03-31:
This is usually a channel configuration issue. You have to configure the channel list on your LoStik to match your gateways frequency plan. There is a configure.py script I created to make this easier. You pass it one of the .conf files (after editing it to match your needs). The example ttn.conf files should configure your channels to the ttn frequency plans.

On Mon, Mar 30, 2020, at 4:17 AM, gudsi wrote:
>

> An update from my side
>  I finally was able to connect with gateway via Termite and lorawan.py via my pc. But I use LoStik on Raspberry, I get denied or no_channel_free.
>  Any ideas what I am doing wrong?

> —
> You are receiving this because you commented.
> Reply to this email directly, view it on GitHub <https://github.com/ronoth/LoStik/issues/24#issuecomment-605939502>, or unsubscribe <https://github.com/notifications/unsubscribe-auth/AAAOZBHNYDDSLVUQFLHOZ23RKB5TZANCNFSM4KBT3W3Q>.

gudsi, 2020-04-08:
Thanks a lot for your help, lolsborn!
I did a big mistake. I did not send a new join after powering the stick again.
Now everything is working fine. Thanks!

Closed 2020-04-08.

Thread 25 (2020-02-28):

Indoor range problem

RHG101997, 2020-02-28:
The last two weeks have been doing some research on LoStick(rn2903) and are really easy to use. Everything is connected and working fine except for the range is 80 meters. I am currently at a University lab.
1 - Using Indoor Dragino Gateway in US. Model LG308
2- For the Power and DateRate I have been using pwridx = 5 and dr = 0.
3 - I did notice the  SNR = -8.9 and RSSI = -125 are kind of high.
4 - I will try a new antenna shortly
The question is what other recommendations to make this range be around a mile.
software? hardware?
Does indoor need some other type of hardware?
Thank you.

Closed 2021-09-01.

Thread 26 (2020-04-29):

Receiver example not working with Arduino MKR WAN 1310

rrbonham96, 2020-04-29:
I'm trying to send basic Lora packets to the LoStik using the radio receiver example using an Arduino running the example radio sender code from [https://github.com/sandeepmistry/arduino-LoRa/blob/master/examples/LoRaSender/LoRaSender.ino](url), but I'm not seeing any data show up on the receiving end. I'm not really sure what I'm doing wrong.

Arduino serial monitor:
`14:34:36.035 -> LoRa Sender
14:34:36.461 -> Sending packet: 0
14:34:41.505 -> Sending packet: 1
14:34:46.534 -> Sending packet: 2
14:34:51.560 -> Sending packet: 3
14:34:56.607 -> Sending packet: 4
14:35:01.643 -> Sending packet: 5
...
`

radio_receiver.py output:
`connection made
RN2903 1.0.5 Nov 06 2018 10:45:27
4294967245
`

lolsborn, 2020-04-30:
Based on that example code there seem to be a lot of things missing. Do you need to specify which pins the SPI is hooked up to on the LoRa module? Spi frequency? Set the coding rate? Spread factor?

On Wed, Apr 29, 2020, at 12:46 PM, Bork wrote:
>

> I'm trying to send basic Lora packets to the LoStik using the radio receiver example using an Arduino running the example radio sender code from https://github.com/sandeepmistry/arduino-LoRa/blob/master/examples/LoRaSender/LoRaSender.ino <https://www.fastmail.com/mail/compose/url>, but I'm not seeing any data show up on the receiving end. I'm not really sure what I'm doing wrong.

> Arduino serial monitor:
> `14:34:36.035 -> LoRa Sender 14:34:36.461 -> Sending packet: 0 14:34:41.505 -> Sending packet: 1 14:34:46.534 -> Sending packet: 2 14:34:51.560 -> Sending packet: 3 14:34:56.607 -> Sending packet: 4 14:35:01.643 -> Sending packet: 5 ...`

> radio_receiver.py output:
> `connection made RN2903 1.0.5 Nov 06 2018 10:45:27 4294967245`

> —
> You are receiving this because you are subscribed to this thread.
> Reply to this email directly, view it on GitHub <https://github.com/ronoth/LoStik/issues/26>, or unsubscribe <https://github.com/notifications/unsubscribe-auth/AAAOZBCQDCH6FLHWHPHFHPLRPB7ZDANCNFSM4MUALWKA>.

rrbonham96, 2020-08-31:
I did some research and finally found the solution to this. The issue wasn't anything to do with SPI since the LoRa module is built into the MKR WAN 1310. I had to set the spread factor on the LoStik to 7 since that's what the Arduino defaults to. I also had to set the sync word to 12 to match the default used by the Arduino. I _think_ that's all it took to get communication up. I am still getting radio_errors for the actual data, but that's a different issue I have yet to look into.

Closed 2020-08-31.

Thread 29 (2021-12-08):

how to recover bricked RN2903 with ICSP?

haimiko, 2021-12-08:
Midway into the firmware update my device lost connection.  The module is now bricked.  How can I leverage the ICSP terminals to recover it like with an Arduino as ISP?

lolsborn, 2021-12-08:
It is a PIC microcontroller and you need a programmer for it.  You can get knock-offs cheap https://www.amazon.com/NOYITO-Microcontrollers-PICkit2-Debugger-Programmer/dp/B07GMH732N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

Microchip provides two separate hex files one is "combined" which includes the bootloader.  If you are flashing via USB you want the other one, but over ICSP you want to use the file which includes bootloader.
________________________________
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

lolsborn, 2021-12-08:
I guess I should mention you'll want to download MPLab IDE for this.
________________________________
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

haimiko, 2021-12-08:
@lolsborn figured it out without the programmer.  Since I bricked it using the USB (bootloader) method the bootloader was still intact.  I found an alternate solution using the Microchip Suite --> Module --> Boot Loader Recover, then loaded the hex file successfully.

Your method would definitely come in handy should I corrupt the bootloader too.  Thank you.

Closed 2021-12-08.

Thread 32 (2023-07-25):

Status mac paused

sainathgorige, 2023-07-25:
Hello,

I'm trying to get coverage of my lora network using losik, I bought two losik, I have tried using lorawan.py, but couldn't succeed.

Following are the steps I followed:

    Generated random unique values(also used sensor values) for DevEUI, AppEUI, and AppKey.
    Registered these values with your LoRaWAN network server(chirpstack dashboard).
    Use these same values in your Python script when running it with the LoStik device.

but the script hung at status ,ac paused:
 sudo python3 lorawan.py /dev/ttyUSB0 --appeui 70B3D57ED0031D3D --appkey EC925802AE430F59798E8C8D7E926C8D --deveui 00D827F000B4C638
Connection to LoStik established
mac set appeui 70B3D57ED0031D3D
mac set appkey EC925802AE430F59798E8C8D7E926C8D
mac set deveui 00D827F000B4C638
mac join otaa
STATUS: ok
STATUS: ok
STATUS: ok
STATUS: mac_paused

is there anything I'm missing

I have also tried using ABP

sudo python3 lorawan.py /dev/ttyUSB0 --joinmode abp --devaddr 010bb971 --nwkskey c44e91483a00aa3cedba46bc4ebe87a8 --appskey d7321ca80503973775a521759f3c5da7
[sudo] password for aerpaw:
Connection to LoStik established
mac set devaddr 010bb971
mac set appskey d7321ca80503973775a521759f3c5da7
mac set nwkskey c44e91483a00aa3cedba46bc4ebe87a8
mac join abp

lolsborn, 2023-07-25:
Did you configure the channels?  What network are you trying to connect to
and what region are you in?

On Tue, Jul 25, 2023 at 9:41 AM sainathgorige ***@***.***>
wrote:

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

sainathgorige, 2023-07-25:
No, How to configure the channels, can you please give a doc/example?

I have 6 RAK lora gateways, which constitutes my lora network. and I'm using US 915mhz.

lolsborn, 2023-07-25:
Take a look at the configure.py script in the examples directory.  It
expects a configuration script like the ttn-us.conf file which is setup for
"The Things Network" with the US channel plan.  You'll need to run that or
manually send the channel commands over to configure them.

On Tue, Jul 25, 2023 at 10:06 AM sainathgorige ***@***.***>
wrote:

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

sainathgorige, 2023-07-25:
Thanks, I have added deveui and app creds to the ttn-us-conf, But still I'm facing the same issue
I have attached the logs to this comment.

[ttn-us.txt](https://github.com/ronoth/LoStik/files/12165835/ttn-us.txt)

[losik_logs.txt](https://github.com/ronoth/LoStik/files/12165829/losik_logs.txt)

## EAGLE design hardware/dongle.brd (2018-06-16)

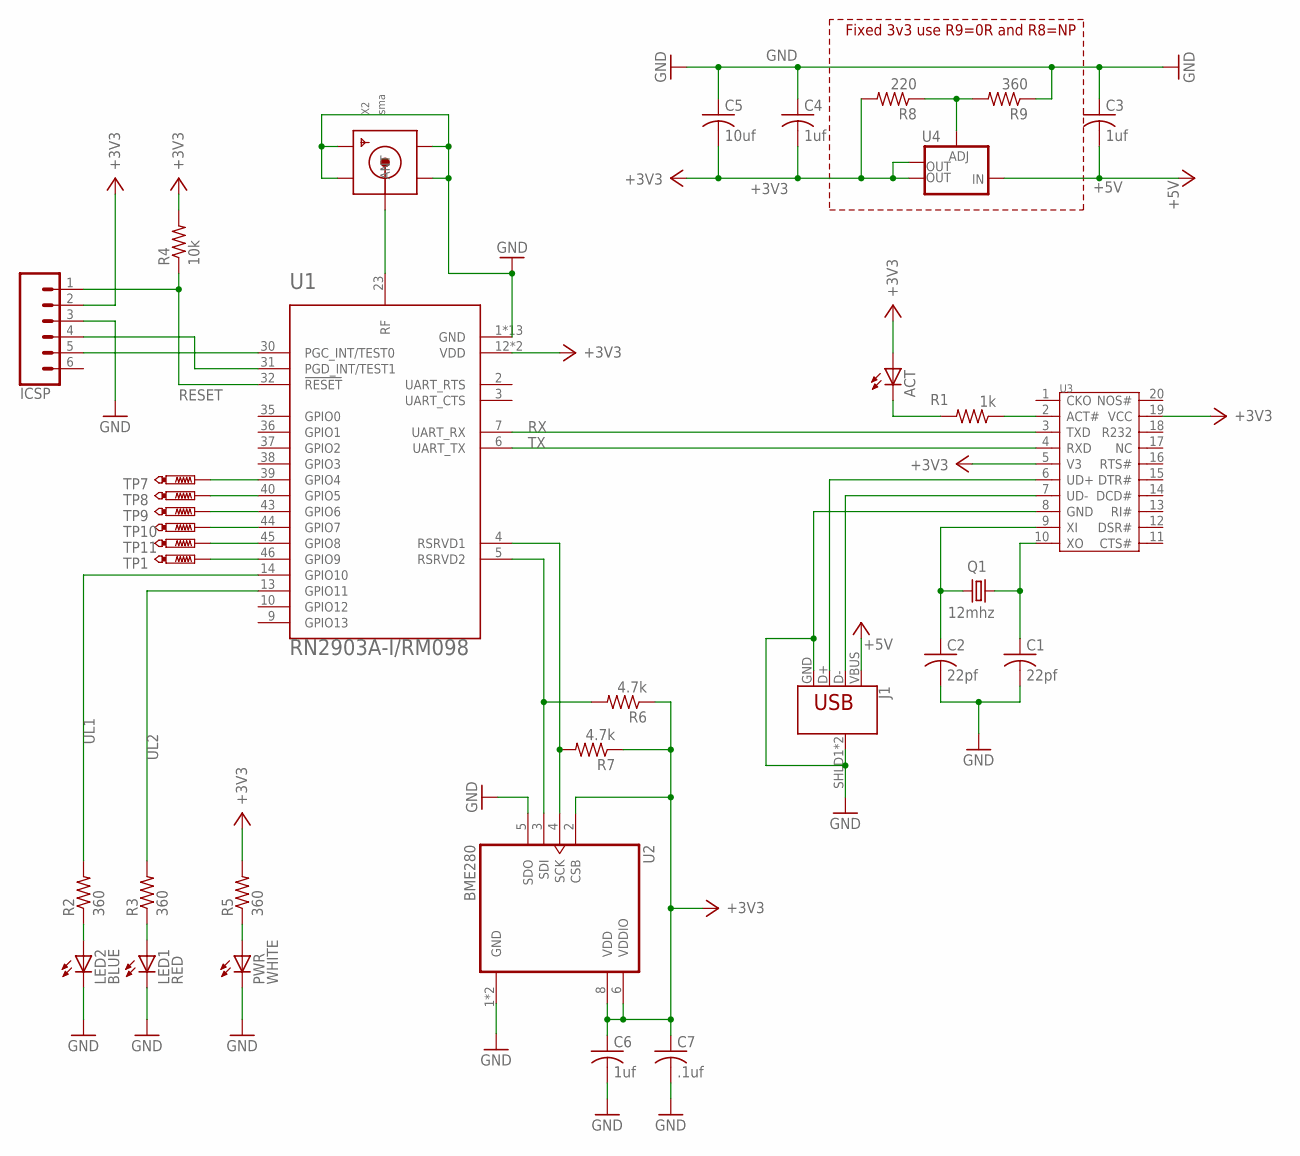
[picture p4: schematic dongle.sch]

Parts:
ACT: LEDCHIP-LED0603; CHIP-LED0603
C1, C2: 22pf; C0603K
C3, C4, C6: 1uf; C0603K
C5: 10uf; C1206K
C7: .1uf; C0603K
ICSP: CONN_06SMD-FEMALE-V2; 1X06-SMD-FEMALE
J1: USB_A_PTH_MALE; USB-A-H
LED1: RED; CHIP-LED0603
LED2: BLUE; CHIP-LED0603
PWR: WHITE; CHIP-LED0603
Q1: 12mhz; SM49
R1: 1k; R0603
R2, R3, R5, R9: 360; R0603
R4: 10k; R0603
R6, R7: 4.7k; R0603
R8: 220; R0603
TP1, TP7, TP8, TP9, TP10, TP11: PTR1B1,27; B1,27
U1: RN2903A-I/RM098; XCVR_RN2903A-I/RM098
U2: BME280; PSON65P250X250X100-8N
U3: INTERFACE-CH340T(SSOP20); SSOP20-0.65-7.6X5.2MM
U4: V_REG_LM1117SOT223; SOT223
X2: sma; SMA_EDGELAUNCH

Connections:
+3V3: ACT.A, C4.2, C5.2, C6.1, C7.1, ICSP.2, R4.2, R5.2, R6.1, R7.1, R8.2, U1.12 (VDD), U1.34 (VDD), U2.2 (CSB), U2.6 (VDDIO), U2.8 (VDD), U3.5 (V3), U3.19 (VCC), U4.2 (OUT), U4.4 (OUT)
+5V: C3.2, J1.VBUS, U4.3 (IN)
GND: C1.2, C2.2, C3.1, C4.1, C5.1, C6.2, C7.2, ICSP.3, J1.GND, J1.SHLD1 (SHIELD), J1.SHLD2 (SHIELD), LED1.C, LED2.C, PWR.C, R9.1, U1.1 (GND), U1.8 (GND), U1.11 (GND), U1.20 (GND), U1.21 (GND), U1.22 (GND), U1.24 (GND), U1.26 (GND), U1.27 (GND), U1.28 (GND), U1.33 (GND), U1.41 (GND), U1.47 (GND), U2.1 (GND), U2.5 (SDO), U2.7 (GND), U3.8 (GND), X2.GND@1 (GND4), X2.GND@2 (GND3), X2.GND@3 (GND2), X2.GND@4 (GND1)
unnamed: U1.23 (RF), X2.P (ANT)
unnamed: R1.1, U3.2 (ACT#)
unnamed: ACT.C, R1.2
unnamed: J1.D+, U3.6 (UD+)
unnamed: J1.D-, U3.7 (UD-)
unnamed: C1.1, Q1.1, U3.10 (XO)
unnamed: C2.1, Q1.2, U3.9 (XI)
unnamed: ICSP.4, U1.31 (PGD_INT/TEST1)
unnamed: ICSP.5, U1.30 (PGC_INT/TEST0)
unnamed: R7.2, U1.4 (RSRVD1), U2.4 (SCK)
unnamed: R6.2, U1.5 (RSRVD2), U2.3 (SDI)
unnamed: LED2.A, R2.1
unnamed: LED1.A, R3.1
unnamed: PWR.A, R5.1
unnamed: TP1.TP, U1.46 (GPIO9)
unnamed: R8.1, R9.2, U4.1 (ADJ)
unnamed: TP7.TP, U1.39 (GPIO4)
unnamed: TP8.TP, U1.40 (GPIO5)
unnamed: TP9.TP, U1.43 (GPIO6)
unnamed: TP10.TP, U1.44 (GPIO7)
unnamed: TP11.TP, U1.45 (GPIO8)
RESET: ICSP.1, R4.1, U1.32 (!RESET)
RX: U1.7 (UART_RX), U3.3 (TXD)
TX: U1.6 (UART_TX), U3.4 (RXD)
UL1: R2.2, U1.14 (GPIO10)
UL2: R3.2, U1.13 (GPIO11)

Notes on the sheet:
Fixed 3v3 use R9=0R and R8=NP

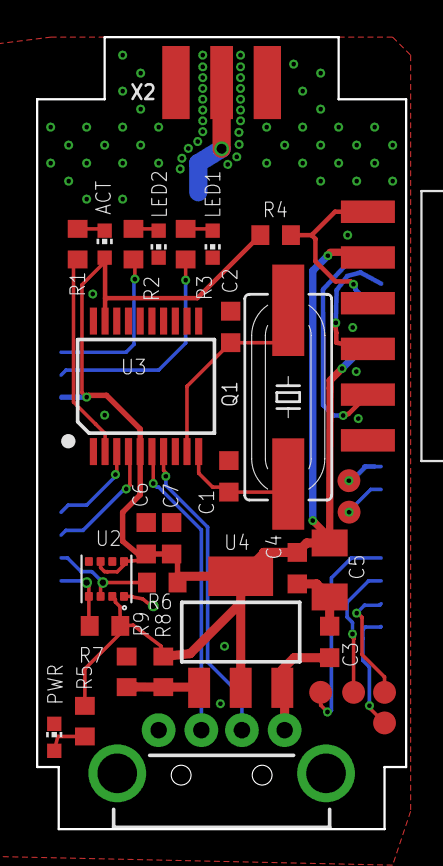
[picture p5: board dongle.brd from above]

Board: 2 copper layers, 20.5 x 44.0 mm, 35 parts (1 on the bottom side), 29 nets.

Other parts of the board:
U$1: 1551USB2

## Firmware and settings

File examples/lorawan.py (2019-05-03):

##!/usr/bin/env python3
import io
import sys
import time
import datetime
import argparse
from enum import IntEnum
import serial
from serial.threaded import LineReader, ReaderThread

parser = argparse.ArgumentParser(description='Connect to LoRaWAN network')
parser.add_argument('port', help="Serial port of LoStik")
parser.add_argument('--joinmode', '-j', help="otaa, abp", default="otaa")

# ABP credentials
parser.add_argument('--appskey', help="App Session Key", default="")
parser.add_argument('--nwkskey', help="Network Session Key", default="")
parser.add_argument('--devaddr', help="Device Address", default="")

# OTAA credentials
parser.add_argument('--appeui', help="App EUI", default="")
parser.add_argument('--appkey', help="App Key", default="")
parser.add_argument('--deveui', help="Device EUI", default="")

args = parser.parse_args()

OTAA_RETRIES = 5

class MaxRetriesError(Exception):
    pass

class ConnectionState(IntEnum):
    SUCCESS = 0
    CONNECTING = 100
    CONNECTED = 200
    FAILED = 500
    TO_MANY_RETRIES = 520


class PrintLines(LineReader):

    retries = 0
    state = ConnectionState.CONNECTING

    def retry(self, action):
        if(self.retries >= OTAA_RETRIES):
            print("Too many retries, exiting")
            self.state = ConnectionState.TO_MANY_RETRIES
            return
        self.retries = self.retries + 1
        action()

    def get_var(self, cmd):
        self.send_cmd(cmd)
        return self.transport.serial.readline()

    def join(self):
        if args.joinmode == "abp":
            self.join_abp()
        else:
            self.join_otaa()

    def join_otaa(self):
        if len(args.appeui):
            self.send_cmd('mac set appeui %s' % args.appeui)
        if len(args.appkey):
            self.send_cmd('mac set appkey %s' % args.appkey)
        if len(args.deveui):
            self.send_cmd('mac set deveui %s' % args.deveui)
        self.send_cmd('mac join otaa')

    def join_abp(self):
            if len(args.devaddr):
                self.send_cmd('mac set devaddr %s' % args.devaddr)
            if len(args.appskey):
                self.send_cmd('mac set appskey %s' % args.appskey) 
            if len(args.nwkskey):
                self.send_cmd('mac set nwkskey %s' % args.nwkskey)
            self.send_cmd('mac join abp')

    def connection_made(self, transport):
        """
        Fires when connection is made to serial port device
        """
        print("Connection to LoStik established")
        self.transport = transport
        self.retry(self.join)

    def handle_line(self, data):
        # if data == "ok" or data == 'busy':
        #     return
        print("STATUS: %s" % data)
        if data.strip() == "denied" or data.strip() == "no_free_ch":
            print("Retrying OTAA connection")
            self.retry(self.join)
        elif data.strip() == "accepted":
            print("UPDATING STATE to connected")
            self.state = ConnectionState.CONNECTED

    def connection_lost(self, exc):
        """
        Called when serial connection is severed to device
        """
        if exc:
            print(exc)
        print("Lost connection to serial device")

    def send_cmd(self, cmd, delay=.5):
        print(cmd)
        self.transport.write(('%s\r\n' % cmd).encode('UTF-8'))
        time.sleep(delay)


ser = serial.Serial(args.port, baudrate=57600)
with ReaderThread(ser, PrintLines) as protocol:
    while protocol.state < ConnectionState.FAILED:
        if protocol.state != ConnectionState.CONNECTED:
            time.sleep(1)
            continue
        protocol.send_cmd("mac tx uncnf 1 %d" % int(time.time()))
        time.sleep(10)
    exit(protocol.state)

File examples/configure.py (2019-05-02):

##!/usr/bin/env python3

import serial
import time
import io
import argparse
import configparser


parser = argparse.ArgumentParser(description='Configure LoStik device')
parser.add_argument('port', help="Serial port of LoStik")
parser.add_argument('config', help="Configuration File")
parser.add_argument('--debug', '-d', help="Print debug output", action='store_const', const=True, default=False)

args = parser.parse_args()

config = configparser.ConfigParser()
config.read(args.config)

ser = serial.Serial(args.port, baudrate=57600, timeout=10)


# Print iterations progress
def printProgressBar (iteration, total, prefix = '', suffix = '', decimals = 1, length = 100, fill = '█'):
    """
    Call in a loop to create terminal progress bar
    @params:
        iteration   - Required  : current iteration (Int)
        total       - Required  : total iterations (Int)
        prefix      - Optional  : prefix string (Str)
        suffix      - Optional  : suffix string (Str)
        decimals    - Optional  : positive number of decimals in percent complete (Int)
        length      - Optional  : character length of bar (Int)
        fill        - Optional  : bar fill character (Str)
    """
    percent = ("{0:." + str(decimals) + "f}").format(100 * (iteration / float(total)))
    filledLength = int(length * iteration // total)
    bar = fill * filledLength + '-' * (length - filledLength)
    print('\r%s |%s| %s%% %s' % (prefix, bar, percent, suffix), end = '\r')
    # Print New Line on Complete
    if iteration == total: 
        print()

# import pdb; pdb.set_trace()
def send_cmd(cmd):
    if args.debug:
        print(cmd)
    ser.write(("%s\r\n"% cmd).encode("UTF-8"))
    time.sleep(.2)

def get_var(cmd):
    send_cmd(cmd)
    var = ser.readline().strip().decode("UTF8")
    if args.debug:
        print(var)
    return var

def set_confirm(cmd):
    res = get_var(cmd)
    if args.debug:
        print(res)

    if res != "ok":
        raise Exception("Error in command: %s\r\n Response: %s" % (cmd, res))

max_ch = 72
sku = "RN2903"

send_cmd('sys get ver')
verinfo = ser.readline().decode("UTF-8")
if not verinfo:
    print("Timeout connecting to device")
    exit()

if("RN2483" in verinfo):
    sku = "RN2483"
    max_ch = 16
elif "RN2903" in verinfo:
    sku = "RN2903"
else:
    raise Exception("Invalid SKU")

config_channels = config.items('channels')
auth_method = config.get('mac', 'auth')

print(verinfo.strip())
print('Auth Method: %s' % auth_method)

if auth_method == 'otaa':
    print('Configuring otaa')
    set_confirm('mac set appeui %s' % config.get('otaa', 'appeui'))
    set_confirm('mac set appkey %s' % config.get('otaa', 'appkey'))
    set_confirm('mac set deveui %s' % config.get('otaa', 'deveui'))
elif auth_method == 'abp':
    print('Configuring apb')
    set_confirm('mac set devaddr %s' % config.get('abp', 'devaddr'))
    set_confirm('mac set nwkskey %s' % config.get('abp', 'nwkskey'))
    set_confrim('mac set appskey %s' % config.get('abp', 'appskey'))
else:
    raise Exception('Invaoid auth method %s' % auth_method)


print("Configuring Channels:")
ch_count = len(config_channels)
i = 0

def update_progress():
    global i
    i = i + 1
    printProgressBar(i, ch_count, "Channels")
    if args.debug:
        print() # extra newline for progress bar

for config_entry in config_channels:
    config_fields = config_entry[1].split(',')
    ch_id = int(config_entry[0].replace("ch", "").strip())

    ch_freq = get_var('mac get ch freq %d' % ch_id)
    config_freq = config_fields[0].replace('"', '').strip()
    if config_freq == '':
        update_progress()
        continue
        if args.debug:
            print("Blank frequency on channel %d, skipping" % ch_id)

    if(len(config_fields) >= 4):
        config_drrange = "%d %d" % (int(config_fields[2]), int(config_fields[3]))
        set_confirm('mac set ch drrange %d %s' % (ch_id, config_drrange))

    if(len(config_fields) >= 5):
        config_dcycle = int(config_fields[4])
        set_confirm('mac set ch dcycle %d %d' % (ch_id, config_dcycle))

    # US SKU has 72 fixed freq channels
    # EU version has only 16 channels, but freq is user configurable on ch 3-15
    if sku == "RN2903":
        if config_freq != ch_freq:
            raise Exception("Frequency %s for channel %s is does not match device." % (config_freq, ch_id))
    else:
        if ch_id < 3:
            if config_freq != ch_freq:
                raise Exception("Frequency %s for channel %s is does not match device." % (config_freq, ch_id))
        else:
            set_confirm('mac set ch freq %d %s' % (ch_id, config_freq))

    config_status = config_fields[1].replace('"', '').strip()
    set_confirm('mac set ch status %d %s' % (ch_id, config_status))
    update_progress()

print("Saving mac settings")
set_confirm('mac save')

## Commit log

2018-06-16 hardware files
    [dongle.brd, dongle.sch]
2018-07-02 Fix "non scriptable" issue
    [blinky.py, radio_reciever.py, radio_sender.py]
2018-12-09 Add info about user leds
    Adding information about user leds in readme per @WA4OSH
2018-12-10 improve sender to show frame count, blink properly
2019-02-25 Rewrite radio_sender example to use serial.threaded.LineReader
2019-05-02 Fixes for lorawan example
    [lorawan.py]
2019-05-03 fix use of status instead of state
    [lorawan.py]

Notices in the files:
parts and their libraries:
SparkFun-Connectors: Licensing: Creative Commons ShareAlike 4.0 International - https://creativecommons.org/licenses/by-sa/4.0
